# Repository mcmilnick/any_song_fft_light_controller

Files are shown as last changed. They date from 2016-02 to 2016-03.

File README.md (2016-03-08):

# any_song_light_controller
Send any song to a Pi, analyze the frequency spectrum, and control light strips.

This project goes with a walkthrough on my website...
https://techtures.wordpress.com/nicks-projects/any-song-christmas-lights/

By the end, you connect to your Pi via bluetooth, send any song, analyze the frenquency spectrum
of the song, and control strands of lights based of it.

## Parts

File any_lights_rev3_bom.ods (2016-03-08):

Part | Value | Quantity | Specs | Manufacturer# | Distributor# | Company | Notes
C1-2 | 10uF | 2 | CAP CER 10UF 6.3V X5R 0603 | CL10A106MQ8NNNC | 1276-1119-1-ND | Samsung
C4 | .1uF | 1 | CAP CER 0.1UF 16V X7R 0603 | C0603C104J4RACTU | 399-1097-1-ND | Kemet
C5-8, 12-14,25 | .1uF | 7 | 0.1UF 16V 10% X5R 0402 | GRM155R61C104KA88D | 490-5415-1-ND | Murata
C9-10 | 4.7uF | 2 | CAP CER 4.7UF 6.3V X5R 0402 | GRM155R60J475ME47D | 490-5915-1-ND | Murata
C11 | 10nF | 1 | 10000PF 50V 10% X7R 0402 | GRM155R71H103KA88D | 490-4516-1-ND | Murata
C15-19 | 1.0uF | 5 | CAP CER 1UF 6.3V X5R 0402 | GRM155R60J105KE19D | 490-1320-1-ND | Murata
C24 | 10uF | 1 | CAP CER 10UF 4V X5R 0402 | GRM155R60G106ME44D | 490-10693-1-ND | Murata
C20-23 | 100uF | 4 | CAP ALUM 100UF 20% 35V RADIAL | 35ZLH100MEFC6.3X11 | 1189-1300-ND | Rubycon
C3 | 470uF | 1 | 470uF 10 Volts 20% Radial | 477CKE010M | 598-477CKE010M | Cornell Dubilier
FB1 | FB | 1 | 30Ohm @100MHz, 10mOhm DC, 0603 | CIS10P300AC | 1276-6353-1-ND | Samsung
R1-2,31-36 | 20k | 2 | RES SMD 20K OHM 1% 1/10W 0603 | RC0603FR-0720KL | 311-20.0KHRCT-ND | Yageo
R3 | 10Ohm | 1 | SMD 1/4W 10ohm 1% | RL1220S-100-F | 754-RL1220S-100-F | Susumu
R4-5 | 100k | 2 | RES SMD 100K OHM 1% 1/8W 0805 | RC0805FR-07100KL | 311-100KCRCT-ND | Yageo
R6 | 560 | 1 | RES SMD 560 OHM 1% 1/10W 0603 | RC0603FR-07560RL | 311-560HRCT-ND | Yageo
R7 | 10K | 1 | 10K OHM 5% 1/4W 0603 | ESR03EZPJ103 | RHM10KDCT-ND | Rohm
R9 | 1M | 1 | SMD 1/10watt 1.0Mohms 1% | CRCW06031M00FKEA | 71-CRCW0603-1.0M-E3 | Vishay
R10 | 100k | 1 | 100K OHM 5% 1/4W 0603 | ESR03EZPJ104 | RHM100KDCT-ND | Rohm
R11-12 | 27R | 2 | RES SMD 27 OHM 1% 1/4W 0603 | ERJ-PA3F27R0V | P27.00BYCT-ND | Panasonic
R13-14 | 1k | 2 | RES SMD 1K OHM 5% 1/10W 0603 | RC0603JR-071KL | 311-1.0KGRCT-ND | Yageo
R30 | 374Ohm | 1 | RES SMD 374 OHM 1% 1/10W 0603 | RC0603FR-07374RL | 311-374HRCT-ND | Yageo
TM1 | 1k POT | 1 | POT 1K OHM 1/4W PLASTIC LINEAR | 3310C-125-102L | 3310C-125-102L-ND | Bournes Inc.
TM2 | 10k POT | 1 | POT 10K OHM 1/4W PLASTIC LINEAR | 3310R-125-103L | 3310R-125-103L-ND | Bournes Inc.
U1,25,26 | Prog Header | 3 | 10POS 2ROW .100Pitch Header | SAM1035-05-ND | SAM1035-05-ND | Amphenol
U5,11 | Red LED | 2 | LED 0402 RED 50MW 20MA SMD | SML-P11UTT86 | 511-1653-1-ND | Rohm
U4 | USB Con | 1 | micro B USB 2.0 5POS | 10118193-0001LF | 609-4616-1-ND | Amphenol
U6 | Resonator | 1 | CSTCE16M0V53-R0 | CSTCE16M0V53-R0 | CSTCE16M0V53-R0 | Murata
U8 | USB/UART | 1 | CSTCE16M0V53-R0 | CSTCE16M0V53-R0 | CSTCE16M0V53-R0 | FTDI
U9 | Diode Array | 1 | TVS Diode 6VWM 13VC SC706 | SP3002-04JTG | F2916TR-ND | Little Fuse
U23 | RN52 Bluetooth | 1 | BLUETOOTH 3.0 CLASS2 AUD | RN52-I/RM116 | RN52-I/RM116-ND | Microchip
U27 | Test Header | 1 | 5pin JTAG Connector | TSW-105-07-T-S | SAM1035-05-ND | Samtec
U$28 | Differential to SE AMP | 1 | IC AMP AUDIO PWR .15W AB 10MSOP | TPA6112A2DGQR | 296-10848-1-ND | TI
U29 | 2 pin Jumper | 1 | 2pin Connector | TSW-102-14-T-S | SAM1059-02-ND | Samtec
U$30 | ATMEGA328P-AURCT | 1 | IC MCU 8BIT 32KB FLASH 32TQFP | ATMEGA328P-AUR | ATMEGA328P-AURCT-ND | Atmel
U31-39 | AC Con | 9 | 738W-CX2-01 | 738W-CX2/01 | Q281-ND | Qualtek
U$40 | 9V Barell Con | 1 | PWR Jack 2x5.5 high | CUI_INC_PF202A | CUI_INC_PF202A | CUI
X2 | 3.5mm Jack | 1 | 3.5mm Jack | Lumberg 1502 01 | 13M3743 | Lumberg
IC1 | Low Voltage AMP | 1 | IC AMP AUDIO PWR 1W MONO AB 8DIP | LM386N-4/NOPB | LM386N-4/NOPB-ND | TI

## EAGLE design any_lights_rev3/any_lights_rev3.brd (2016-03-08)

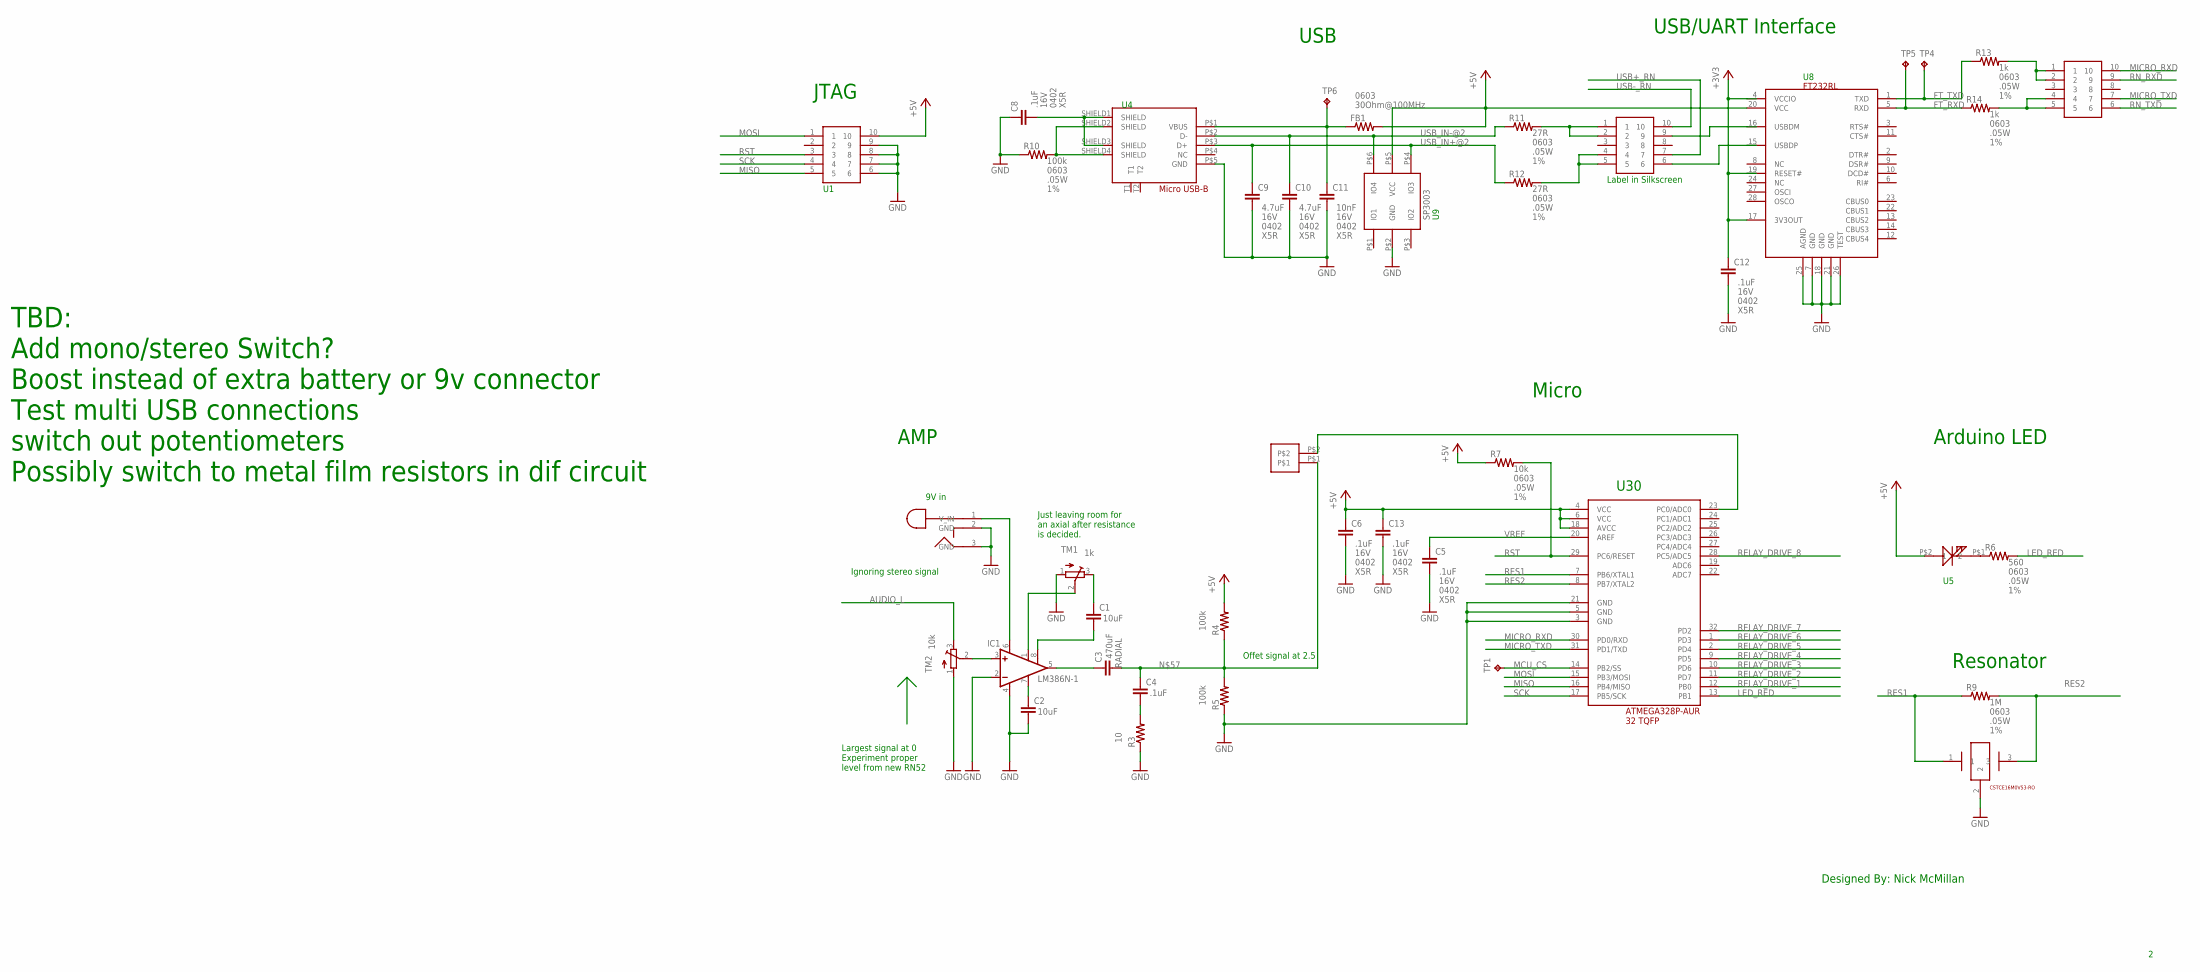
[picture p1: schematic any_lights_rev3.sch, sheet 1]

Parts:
C1, C2, C4: CC0603; C0603
C3: C5/3; C5B3
C5, C6, C8, C9, C10, C11, C12, C13: CC0402; C0402; RATING X5R; TOLERANCE 16V
FB1: R-US_R0603; R0603
IC1: LM386N-1; DIL08
R3, R4, R5: R-US_M0805; M0805
R6, R7, R9, R10, R11, R12, R13, R14: R-US_R0603; R0603; TOLERANCE 1%
TM1, TM2: TRIMPOT3386; TRIM-3386
TP1: TPB1,27; B1,27
TP4, TP5, TP6: TPB2,54; B2,54
U$1, U$25, U$26: 10PINHEADER
U$4: MICRO_USB_B; MICRO_USB_B_CON
U$5: SML-P11UTT86
U$6: CSTCE16M0V53-R0
U$8: FT232RL
U$9: SP3003-SC70-5; SP3003
U$29: SAMTEC2X1; 2PHEADER
U$30: ATMEGA328P-AURCT; ATMEGA328P-AURCT(32PIN)
U$40: CUI_INC_PF202A

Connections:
+3V3: C12.1, U$8.4 (VCCIO), U$8.17 (3V3OUT), U$8.19 (RESET#); also elsewhere on the board
+5V: C6.1, C13.1, FB1.2, R4.2, R7.1, U$1.10, U$5.P$2 (1), U$8.20 (VCC), U$9.P$5 (VCC), U$30.4 (VCC), U$30.6 (VCC), U$30.18 (AVCC)
AUDIO_L: TM2.3 (E); also elsewhere on the board
FT_RXD: R14.1, TP5.TP, U$8.5 (RXD)
FT_TXD: R13.1, TP4.TP, U$8.1 (TXD)
GND: C2.2, C5.2, C6.2, C8.1, C9.2, C10.2, C11.2, C12.2, C13.2, IC1.2 (-IN), IC1.4 (GND), R3.1, R5.1, R10.1, TM1.1 (A), TM2.1 (A), U$1.6, U$1.7, U$1.8, U$1.9, U$4.P$5 (GND), U$6.2, U$8.7 (GND), U$8.18 (GND), U$8.21 (GND), U$8.25 (AGND), U$8.26 (TEST), U$9.P$2 (GND), U$30.3 (GND), U$30.5 (GND), U$30.21 (GND), U$40.2 (GND), U$40.3 (GND); also elsewhere on the board
LED_RED: R6.2, U$30.13 (PB1)
MCU_CS: TP1.TP, U$30.14 (PB2/SS)
MICRO_RXD: U$26.10, U$30.30 (PD0/RXD)
MICRO_TXD: U$26.7, U$30.31 (PD1/TXD)
MISO: U$1.5, U$30.16 (PB4/MISO)
MOSI: U$1.1, U$30.15 (PB3/MOSI)
unnamed: IC1.3 (+IN), TM2.2 (S)
unnamed: C1.1, TM1.3 (E)
unnamed: IC1.1 (GAIN), TM1.2 (S)
unnamed: C2.1, IC1.7 (BYPASS)
unnamed: C1.2, IC1.8 (GAIN)
unnamed: IC1.6 (VS), U$40.1 (V_IN)
unnamed: C3.1, IC1.5 (OUT)
unnamed: R12.2, U$25.4, U$25.5
unnamed: C4.2, R3.2
unnamed: C8.2, U$4.SHIELD1 (SHIELD), U$4.SHIELD3 (SHIELD)
unnamed: R11.2, U$25.1, U$25.2
unnamed: R13.2, U$26.1, U$26.2
unnamed: R14.2, U$26.4, U$26.5
unnamed: R10.2, U$4.SHIELD2 (SHIELD), U$4.SHIELD4 (SHIELD)
unnamed: R6.1, U$5.P$1 (2)
unnamed: C3.2, C4.1, R4.1, R5.2, U$29.P$1
RELAY_DRIVE_1: U$30.12 (PB0)
RELAY_DRIVE_2: U$30.11 (PD7)
RELAY_DRIVE_3: U$30.10 (PD6)
RELAY_DRIVE_4: U$30.9 (PD5)
RELAY_DRIVE_5: U$30.2 (PD4)
RELAY_DRIVE_6: U$30.1 (PD3)
RELAY_DRIVE_7: U$30.32 (PD2)
RELAY_DRIVE_8: U$30.28 (PC5/ADC5)
RES1: R9.1, U$6.1, U$30.7 (PB6/XTAL1)
RES2: R9.2, U$6.3, U$30.8 (PB7/XTAL2)
RN_RXD: U$26.9; also elsewhere on the board
RN_TXD: U$26.6; also elsewhere on the board
RST: R7.2, U$1.3, U$30.29 (PC6/RESET)
SCK: U$1.4, U$30.17 (PB5/SCK)
SIGNAL_OUT: U$29.P$2, U$30.23 (PC0/ADC0)
USB+_FT: U$8.15 (USBDP), U$25.6
USB+_RN: U$25.7; also elsewhere on the board
USB-_FT: U$8.16 (USBDM), U$25.9
USB-_RN: U$25.10; also elsewhere on the board
USB_IN+@2: C9.1, R12.1, U$4.P$3 (D+), U$9.P$4 (IO3)
USB_IN-@2: C10.1, R11.1, U$4.P$2 (D-), U$9.P$6 (IO4)
VBUS: C11.1, FB1.1, TP6.TP, U$4.P$1 (VBUS)
VREF: C5.1, U$30.20 (AREF)

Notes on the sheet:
USB
Arduino LED
Resonator
JTAG
USB/UART Interface
Ignoring stereo signal
Largest signal at 0 Experiment proper level from new RN52
Offet signal at 2.5
Micro
AMP
Designed By: Nick McMillan
TBD: Add mono/stereo Switch? Boost instead of extra battery or 9v connector Test multi USB connections switch out potentiometers Possibly switch to metal film resistors in dif circuit
Label in Silkscreen
Just leaving room for an axial after resistance is decided.
9V in
U30

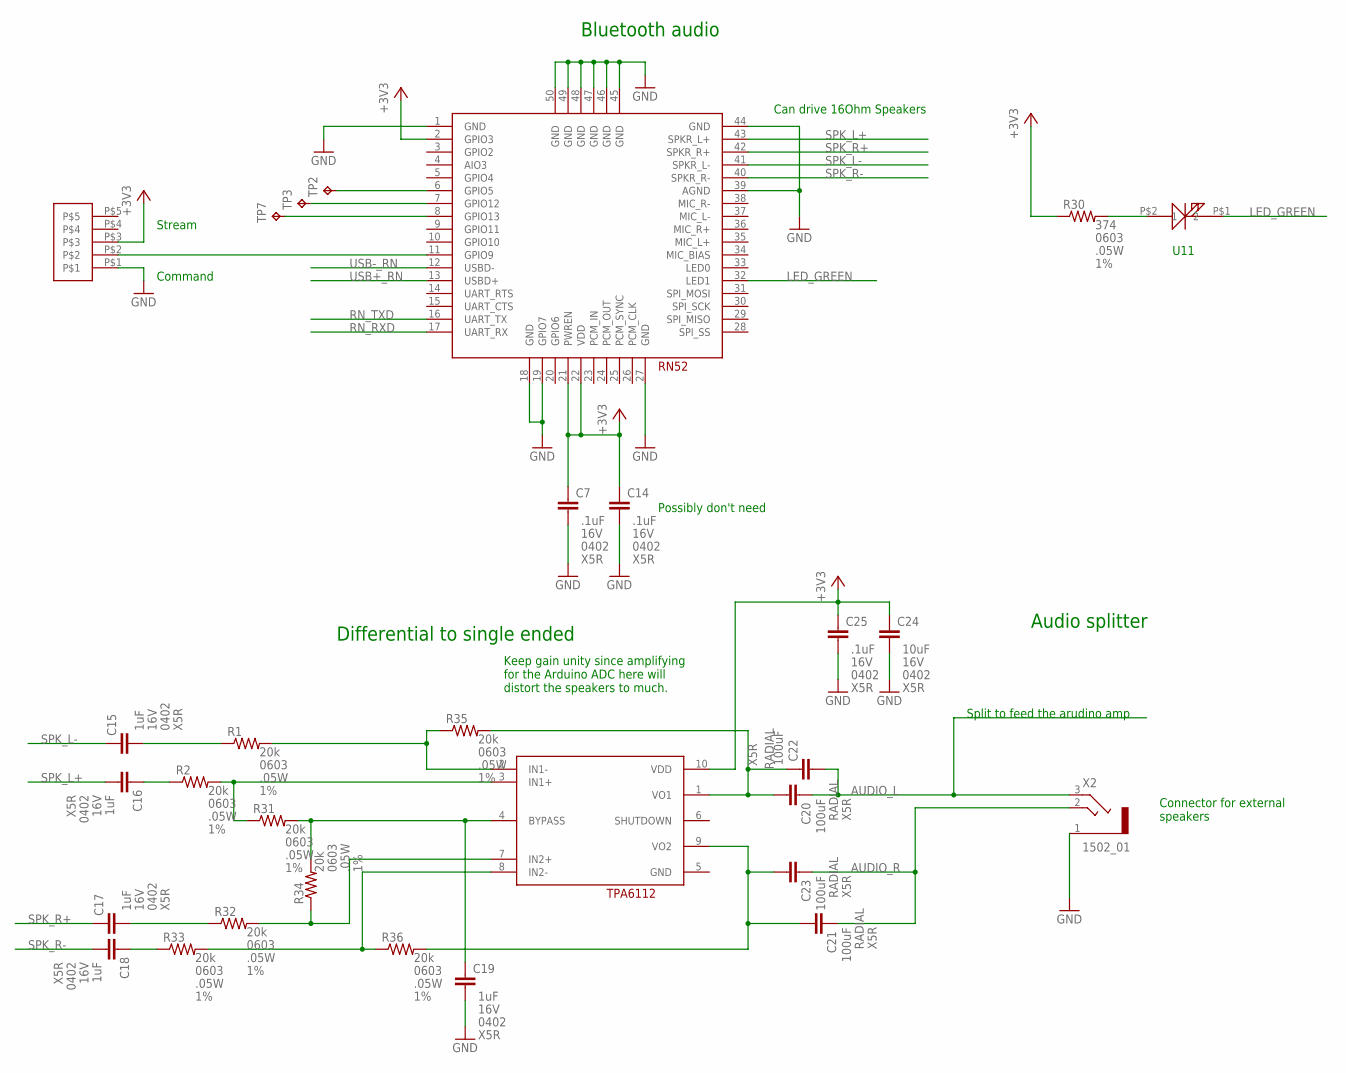
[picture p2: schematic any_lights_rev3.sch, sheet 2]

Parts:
C7, C14, C15, C16, C17, C18, C19, C24, C25: CC0402; C0402; RATING X5R; TOLERANCE 16V
C20, C21, C22, C23: C5/3; C5B3; RATING X5R
R1, R2, R30, R31, R32, R33, R34, R35, R36: R-US_R0603; R0603; TOLERANCE 1%
TP2, TP3, TP7: TPB1,27; B1,27
U$11: SML-P11UTT86
U$23: RN52
U$27: SAMTEC1X5; 5XHEADER
U$28: TPA6112
X2: 1502_01

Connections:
+3V3: C7.1, C14.1, C24.1, C25.1, R30.1, U$23.2 (GPIO3), U$23.21 (PWREN), U$23.22 (VDD), U$27.P$3, U$28.10 (VDD); also elsewhere on the board
AUDIO_L: C20.1, C22.2, X2.3 (2); also elsewhere on the board
AUDIO_R: C21.1, C23.1, X2.2 (3)
GND: C7.2, C14.2, C19.2, C24.2, C25.2, U$23.1 (GND), U$23.18 (GND), U$23.19 (GPIO7), U$23.27 (GND), U$23.39 (AGND), U$23.44 (GND), U$23.45 (GND), U$23.46 (GND), U$23.47 (GND), U$23.48 (GND), U$23.49 (GND), U$23.50 (GND), U$27.P$1, X2.1; also elsewhere on the board
LED_GREEN: U$11.P$1 (2), U$23.32 (LED1)
unnamed: R30.2, U$11.P$2 (1)
unnamed: U$23.11 (GPIO9), U$27.P$2
unnamed: R1.2, R35.1, U$28.2 (IN1-)
unnamed: TP2.TP, U$23.6 (GPIO5)
unnamed: TP3.TP, U$23.7 (GPIO12)
unnamed: TP7.TP, U$23.8 (GPIO13)
unnamed: C15.2, R1.1
unnamed: R2.2, R31.1, U$28.3 (IN1+)
unnamed: C16.1, R2.1
unnamed: R32.2, R34.1, U$28.7 (IN2+)
unnamed: R33.2, R36.1, U$28.8 (IN2-)
unnamed: C18.1, R33.1
unnamed: C17.2, R32.1
unnamed: C19.1, R31.2, R34.2, U$28.4 (BYPASS)
unnamed: C20.2, C22.1, R35.2, U$28.1 (VO1)
unnamed: C21.2, C23.2, R36.2, U$28.9 (VO2)
RN_RXD: U$23.17 (UART_RX); also elsewhere on the board
RN_TXD: U$23.16 (UART_TX); also elsewhere on the board
SPK_L+: C16.2, U$23.43 (SPKR_L+)
SPK_L-: C15.1, U$23.41 (SPKR_L-)
SPK_R+: C17.1, U$23.42 (SPKR_R+)
SPK_R-: C18.2, U$23.40 (SPKR_R-)
USB+_RN: U$23.13 (USBD+); also elsewhere on the board
USB-_RN: U$23.12 (USBD-); also elsewhere on the board

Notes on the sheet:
Bluetooth audio
Differential to single ended
Can drive 16Ohm Speakers
Stream
Command
Possibly don't need
Connector for external speakers
Split to feed the arudino amp
Keep gain unity since amplifying for the Arduino ADC here will distort the speakers to much.
Audio splitter
U11

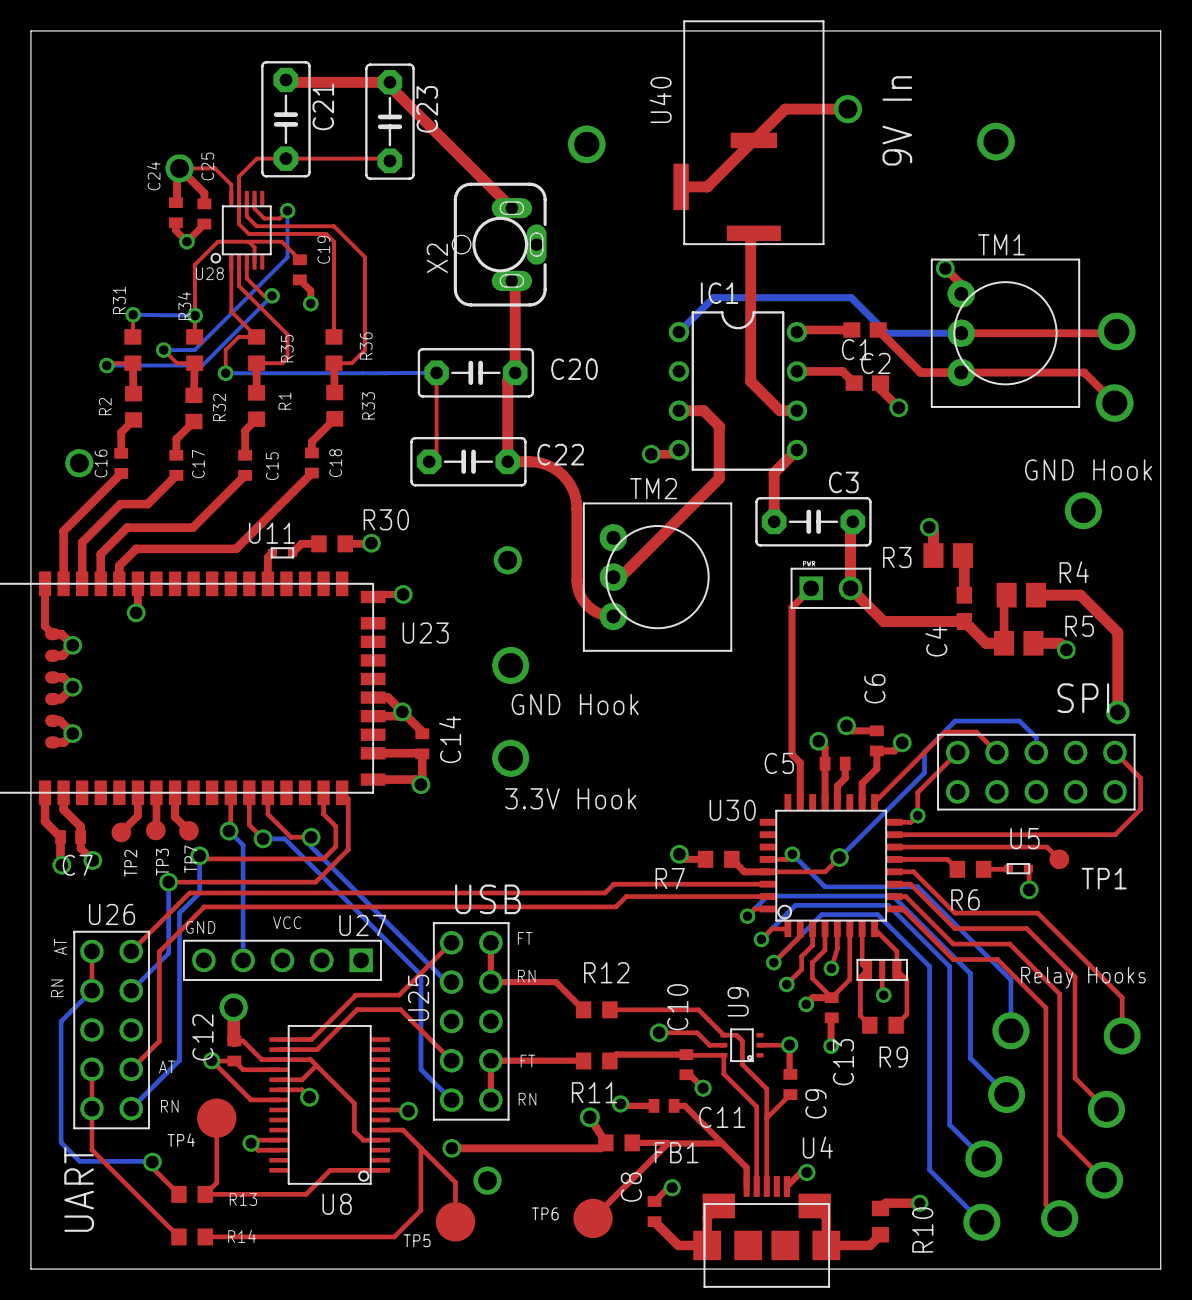
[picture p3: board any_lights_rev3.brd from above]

Board: 4 copper layers, 73.0 x 80.0 mm, 72 parts (0 on the bottom side), 65 nets.

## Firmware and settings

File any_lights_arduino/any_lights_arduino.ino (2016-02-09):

#include <stdio.h>
#include <avr/io.h>
#include <math.h>
#include <util/delay.h>

#define SAMPLING_RATE 128000  //dependent on ADC prescaler
#define BINS 8
#define BLOCK_SIZE 100

volatile int ADC_flag;
volatile int sig_in_10bit;
int freq_pins[BINS] = {0,1,2,3,4,5,6,7};
float Q0, Q1, Q2;

void setup()
{
  for(uint8_t i = 0; i < BINS; i++)
  {
    pinMode(freq_pins[i], OUTPUT);
  }
  InitADC();
  loop();
}

void loop()
{
  float *coeff_array; //don't need to return the sin, cos for the optimized filter
  uint8_t sig_in_count = 0;
  float mag_square[BINS];
  int ADC_data[BLOCK_SIZE];

  coeff_array = calc_coeffs();

  while (1)
  {
    if (ADC_flag == 1) //ADC flag
    {
      ADC_flag = 0;
      //All ADC data is read in as a percentage of GND to VCC. EX: 5V supply - 5V = 1, 2.5V = .5.
      ADC_data[sig_in_count] = sig_in_10bit;
      sig_in_count++;
    }
    //Timing of whenever is noticable to a human.
    if (sig_in_count == 100)
    {
      sig_in_count = 0; //new_block
      for (uint8_t i = 0; i < BINS; i++) //loops for each center frequency
      {
        Q2 = 0;
        Q1 = 0; //reset vars on block begin
        for (uint8_t j = 0; j < BLOCK_SIZE; j++) //loops for each sample in a block
        {
          get_filter_coefficient(ADC_data[j], coeff_array[i]);
        }
        //Find mag after going through block. Deal with squared for less processing.
        mag_square[i] = GetMagnitudeSquared(coeff_array[i]);
        
        //interpet magnitude of each bin
        (mag_square[i] > 4000000) ? digitalWrite(freq_pins[i], HIGH):
                                    digitalWrite(freq_pins[i], LOW);
      }
    }
  }
}


/*-------------------------------------------------------------------------------------
   Functions pertaining to ADC function
  ------------------------------------------------------------------------------------*/
void InitADC()
{
  //ADLAR shift bit is default right. This is fine for 10 bit
  //ADMUX bottom 4 not set gives A0
  ADCSRA = ADCSRB = 0; //clear regs
  ADMUX |= (1 << REFS0); //set ref to AVcc
  ADCSRA |= (1 << ADATE); //auto trigger bit
  ADCSRA |= (1 << ADIE); //enable interrupt
  ADCSRB &= (0 << ADTS2) | (0 << ADTS1) | (0 << ADTS0); //clear bottom 3 for free running mode
  ADCSRA |= (1 << ADPS2) | (1 << ADPS1) | (1 << ADPS0) | (1 << ADEN); //set prescaller to 128kHz and en ADC
  sei(); //global interrupts
  ADC_flag = 0;
  ADCSRA |= (1 << ADSC); //start conversion
}

ISR(ADC_vect)
{
  ADC_flag = 1;
  //Read low register. Locks ADC update until ADCH is read
  sig_in_10bit = ADCL | (ADCH << 8); //10 bit grab. Otherwise no H and shift left.
}


/*-------------------------------------------------------------------------------------
   Functions pertaining to Goertzel filtering
  ------------------------------------------------------------------------------------*/

//Initial calculation of coefficients. There is one for every bin's center freq.
float * calc_coeffs(void)
{
  //the frequency range of interest is 20-5kHz. With 12 bins, we have 416Hz wide bins. We will center on each bin.
  float target_freqs[] = {208, 624, 1040, 1456, 1872, 2288,
                          2704, 3120, 3536, 3952, 4368, 4784
                         };
  float w[12], twok[12], sin_array[12], cos_array[12];
  static float coeff_array[12];

  for (uint8_t bins_num = 0; bins_num < BINS; bins_num++)
  {
    twok[bins_num] = 1 + (2 * ((BINS * target_freqs[bins_num]) / SAMPLING_RATE));
    w[bins_num] = (PI * twok[bins_num]) / BINS;
    sin_array[bins_num] = sin(w[bins_num]);
    cos_array[bins_num] = cos(w[bins_num]);
    coeff_array[bins_num] = 2 * cos_array[bins_num];
  }
  return coeff_array;
}

//Need new coefficient calc for every sample in a block
void get_filter_coefficient(int ADC_data, float coeff)
{
  Q0 = ADC_data + ((float)coeff * Q1) - Q2;
  Q2 = Q1;
  Q1 = Q0;
}

//Optimized algorithm cuts phase info.
float GetMagnitudeSquared(float coeff)
{
  float result = (Q1 * Q1) + (Q2 * Q2) - (Q1 * Q2 * coeff);
  return result;
}


//TBD: get rid of floats. They take to long.

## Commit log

2016-02-05 Adding schematic and simulation
2016-02-05 Schematic didn't upload correctly
2016-02-05 Adding schematic reduced size
2016-02-05 adding arduino code
2016-02-08 Modified Goertzel algorithm with floating point. Would like to get rid of this, but precision is necessary for now and the code is already fast enough. Also added pin drive portion depending on the m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
2016-02-09 changed arduino code
    Cut debug and changed the trigger magnitude.
2016-03-08 Spinning a custom board
    Added initial consolidated schematic and PCB as rev2 and cheap proto
    version as rev3. Also includes BOMs for both.
    [any_lights_rev2.brd, any_lights_rev2.sch, any_lights_rev2_bom.ods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]
